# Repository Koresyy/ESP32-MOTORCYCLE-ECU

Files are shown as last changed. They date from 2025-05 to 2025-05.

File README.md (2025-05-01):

# ESP32-MOTORCYCLE-ECU (HARDWARE ONLY)

📌 THIS BOARD IS INTENDED FOR PROTOTYPING PURPOSES ONLY.  
📌 NO SOFTWARE/CODE IS INCLUDED IN THIS REPOSITORY.  
📌 THIS PROJECT FOCUSES EXCLUSIVELY ON THE HARDWARE DESIGN OF A MOTORCYCLE FUEL CONTROL SYSTEM USING ESP32.

## ⚙️ Overview

This project presents a **custom-designed PCB and schematic** for a fuel injection controller using the ESP32 microcontroller. It is suitable for small-displacement motorcycles and is designed with expandability in mind.




### Key Highlights
- Designed to handle RPM, MAP, IAT, TPS sensor inputs
- Injector driver circuit (compatible with Mio J injector)
- Power supply filtering and protection
- UART/I2C communication interface between controllers
- Expansion pins for future modules (e.g., speedometer, data logger)

## 🔒 Disclaimer

🚨 **THIS IS NOT A PRODUCTION-READY ECU.**  
This board is for **educational and prototyping use only**. Use with caution.  
Author is not responsible for any damage caused by misuse or improper wiring.

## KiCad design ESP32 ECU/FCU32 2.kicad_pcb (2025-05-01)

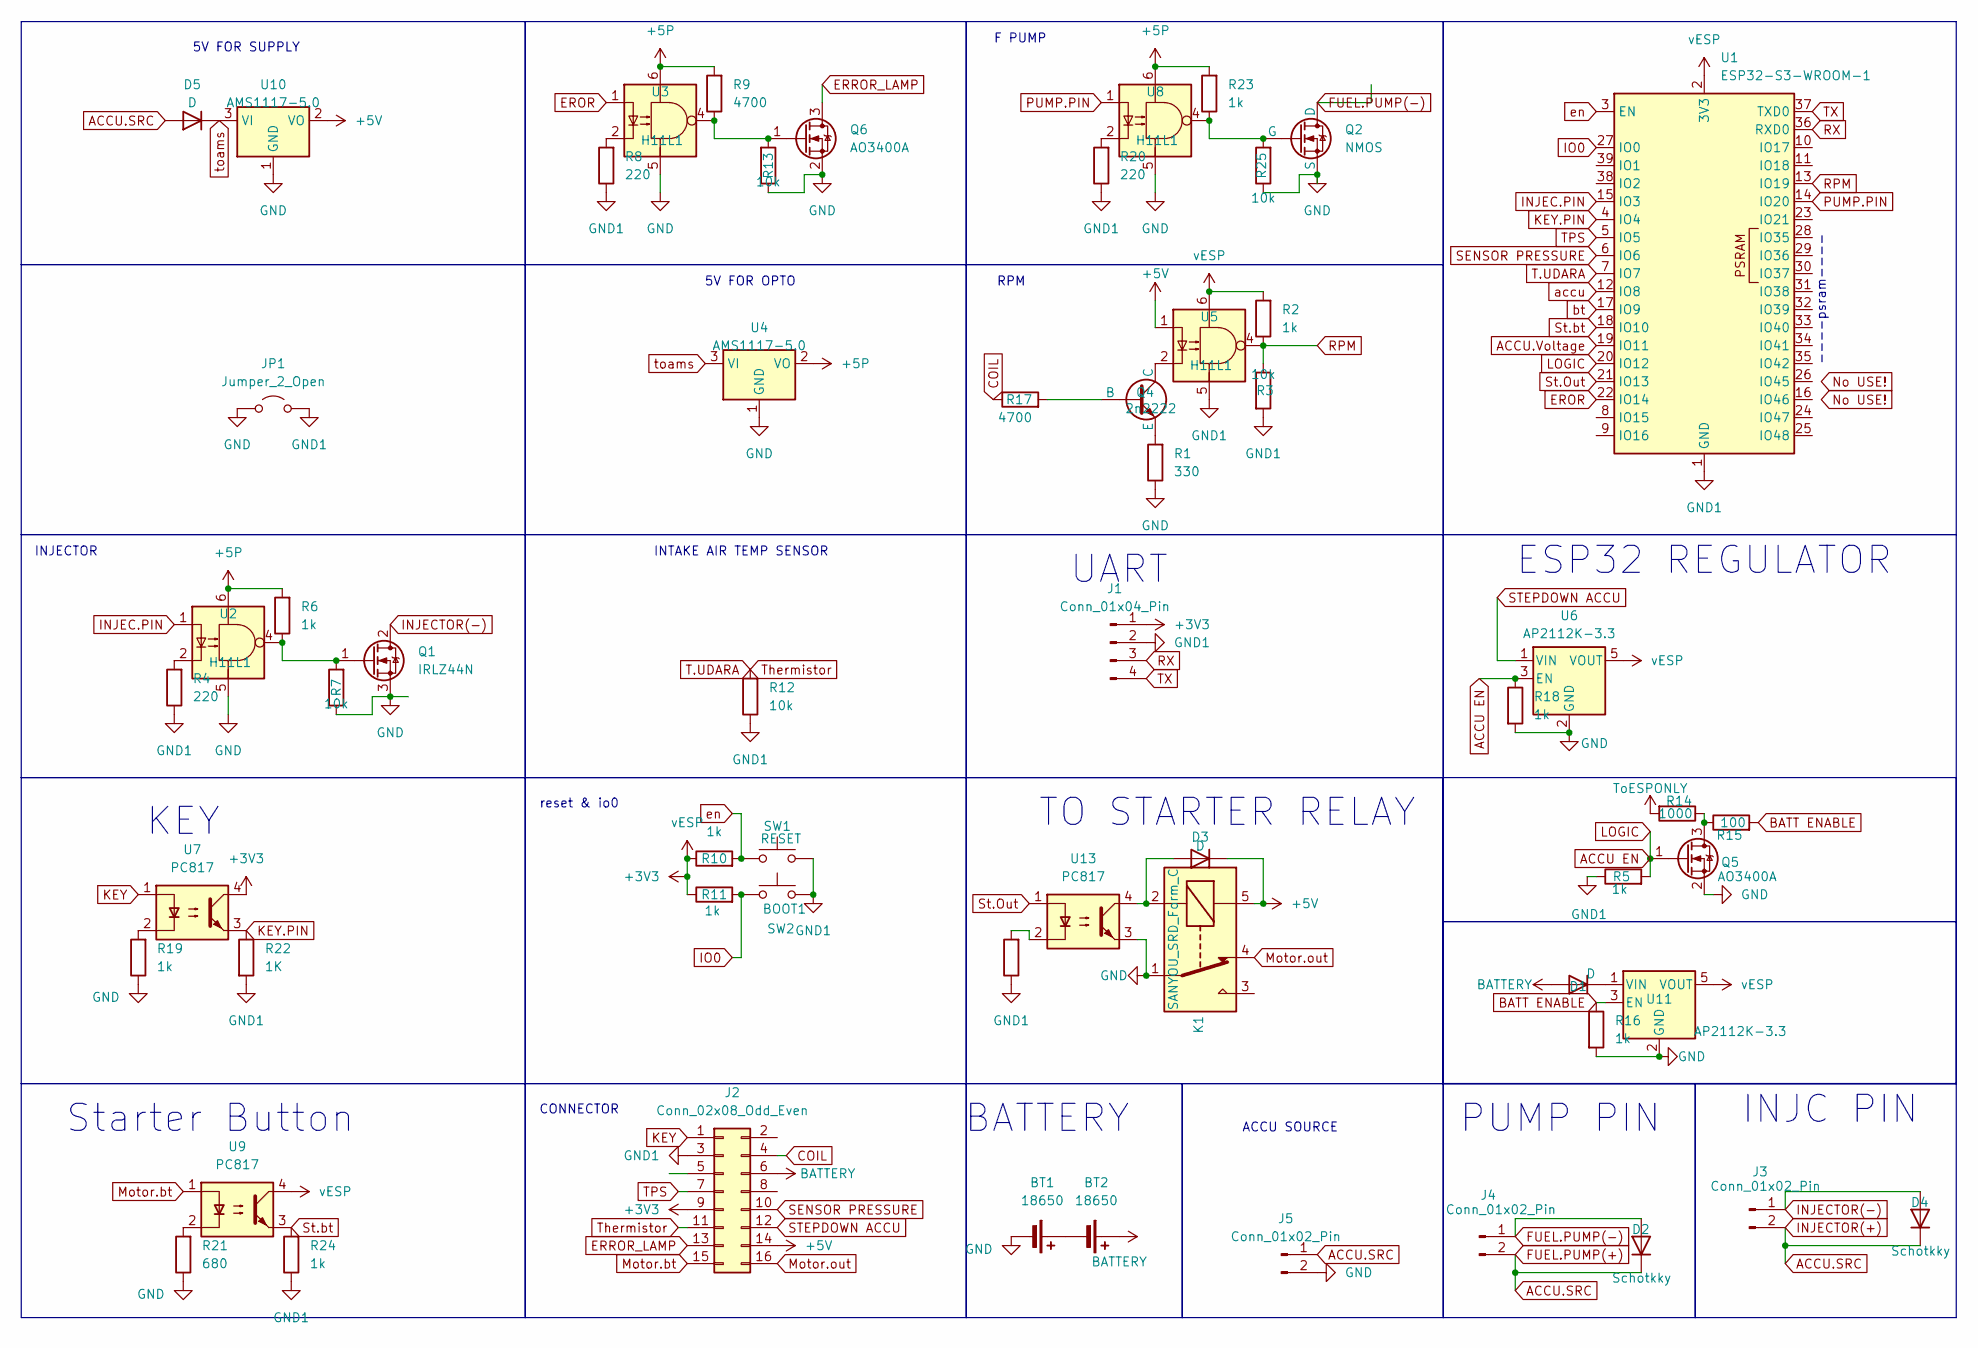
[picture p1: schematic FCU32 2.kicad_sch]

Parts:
BT1, BT2: 18650
D1, D3, D5: D; D_SMA
D2, D4: Schotkky; D_SMA
J1: Conn_01x04_Pin; PinHeader_1x04_P2.54mm_Horizontal
J2: Conn_02x08_Odd_Even; PinHeader_2x08_P2.54mm_Horizontal
J3, J4, J5: Conn_01x02_Pin; AMASS_XT30PW-M_1x02_P2.50mm_Horizontal
JP1: Jumper_2_Open; PinHeader_1x02_P2.54mm_Vertical
K1: SANYOU_SRD_Form_C; Relay_SPDT_SANYOU_SRD_Series_Form_C
Q1: IRLZ44N; TO-220-3_Vertical
Q2: NMOS; TO-252-2
Q4: 2n2222; SOT-23
Q5, Q6: AO3400A; SOT-23
R1: 330; R_1206_3216Metric_Pad1.30x1.75mm_HandSolder
R2, R5, R6, R10, R11, R16, R18, R19, R23, R24: 1k; R_1206_3216Metric_Pad1.30x1.75mm_HandSolder
R3, R7, R12, R13, R25: 10k; R_1206_3216Metric_Pad1.30x1.75mm_HandSolder
R4, R8, R20, R26: 220; R_1206_3216Metric_Pad1.30x1.75mm_HandSolder
R9, R17: 4700; R_1206_3216Metric_Pad1.30x1.75mm_HandSolder
R14: 1000; R_1206_3216Metric_Pad1.30x1.75mm_HandSolder
R15: 100; R_1206_3216Metric_Pad1.30x1.75mm_HandSolder
R21: 680; R_1206_3216Metric_Pad1.30x1.75mm_HandSolder
R22: 1K; R_1206_3216Metric_Pad1.30x1.75mm_HandSolder
SW1: RESET; SW_PUSH_6mm_H4.3mm
SW2: BOOT1; SW_PUSH_6mm_H4.3mm
U1: ESP32-S3-WROOM-1
U2, U3, U5, U8: H11L1; DIP-6_W7.62mm
U4, U10: AMS1117-5.0; SOT-223-3_TabPin2
U6, U11: AP2112K-3.3; SOT-23-5
U7, U9, U13: PC817; DIP-4_W7.62mm

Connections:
+3V3: J1.1, J2.9, R2.2, R10.1, R11.1, U1.2 (3V3), U5.6, U6.5 (VOUT), U7.4, U9.4, U11.5 (VOUT)
+5P: R6.2, R9.2, R23.2, U2.6, U3.6, U4.2 (VO), U8.6
+5V: D3.1 (K), J2.14, K1.5, U5.1, U10.2 (VO)
ACCU EN: Q5.1 (G), R5.2, R18.1, U1.20 (IO12), U6.3 (EN)
ACCU.SRC: D2.1 (K), D4.1 (K), D5.2 (A), J3.2, J4.2, J5.1
ACCU.Voltage: U1.19 (IO11)
BATT ENABLE: R15.2, R16.1, U11.3 (EN)
BATTERY: BT2.1 (+), D1.2 (A), J2.6
COIL: J2.4, R17.1
EROR: U1.22 (IO14), U3.1
ERROR_LAMP: J2.13, Q6.3 (D)
FUEL.PUMP(-): D2.2 (A), J4.1, Q2.1 (D)
GND: BT1.2 (-), J5.2, JP1.1 (A), K1.1, Q1.3 (S), Q2.3 (S), Q5.2 (S), Q6.2 (S), R1.1, R7.1, R13.1, R16.2, R18.2, R19.1, R21.1, R25.1, U2.5, U3.5, U4.1 (GND), U6.2 (GND), U8.5, U10.1 (GND), U11.2 (GND), U13.3
GND1: J1.2, J2.3, JP1.2 (B), R3.2, R4.1, R5.1, R8.1, R12.1, R20.1, R22.2, R24.1, R26.1, SW1.2, SW2.2, U1.1 (GND), U1.40 (GND), U1.41 (GND), U5.5
INJEC.PIN: U1.15 (IO3), U2.1
INJECTOR(-): D4.2 (A), J3.1, Q1.2 (D)
IO0: R11.2, SW2.1, U1.27 (IO0)
KEY: J2.1, U7.1
KEY.PIN: R22.1, U1.4 (IO4), U7.3
Motor.bt: J2.15, U9.1
Motor.out: J2.16, K1.4
unnamed: BT1.1 (+), BT2.2 (-)
unnamed: D1.1 (K), U11.1 (VIN)
unnamed: D3.2 (A), K1.2, U13.4
unnamed: Q1.1 (G), R6.1, R7.2, U2.4
unnamed: Q2.2 (G), R23.1, R25.2, U8.4
unnamed: Q4.2 (B), R17.2
unnamed: Q4.1 (C), U5.2
unnamed: Q4.3 (E), R1.2
unnamed: Q5.3 (D), R14.1, R15.1
unnamed: Q6.1 (G), R9.1, R13.2, U3.4
unnamed: R4.2, U2.2
unnamed: R8.2, U3.2
unnamed: R19.2, U7.2
unnamed: R20.2, U8.2
unnamed: R21.2, U9.2
unnamed: R26.2, U13.2
PUMP.PIN: U1.14 (IO20), U8.1
RPM: R2.1, R3.1, U1.13 (IO19), U5.4
RX: J1.3, U1.36 (RXD0)
SENSOR PRESSURE: J2.10, U1.6 (IO6)
STEPDOWN ACCU: J2.12, U6.1 (VIN)
St.Out: U1.21 (IO13), U13.1
St.bt: R24.2, U1.18 (IO10), U9.3
T.UDARA: J2.11, R12.2, U1.7 (IO7)
TPS: J2.7, U1.5 (IO5)
TX: J1.4, U1.37 (TXD0)
ToESPONLY: R14.2
accu: U1.12 (IO8)
bt: U1.17 (IO9)
en: R10.2, SW1.1, U1.3 (EN)
toams: D5.1 (K), U4.3 (VI), U10.3 (VI)

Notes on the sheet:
ACCU SOURCE
reset & io0
Starter Button
ESP32 REGULATOR
----psram----
UART
TO STARTER RELAY
INJC PIN
5V FOR OPTO
F PUMP
5V FOR SUPPLY
INTAKE AIR TEMP SENSOR
PUMP PIN
CONNECTOR
BATTERY
INJECTOR
KEY
RPM

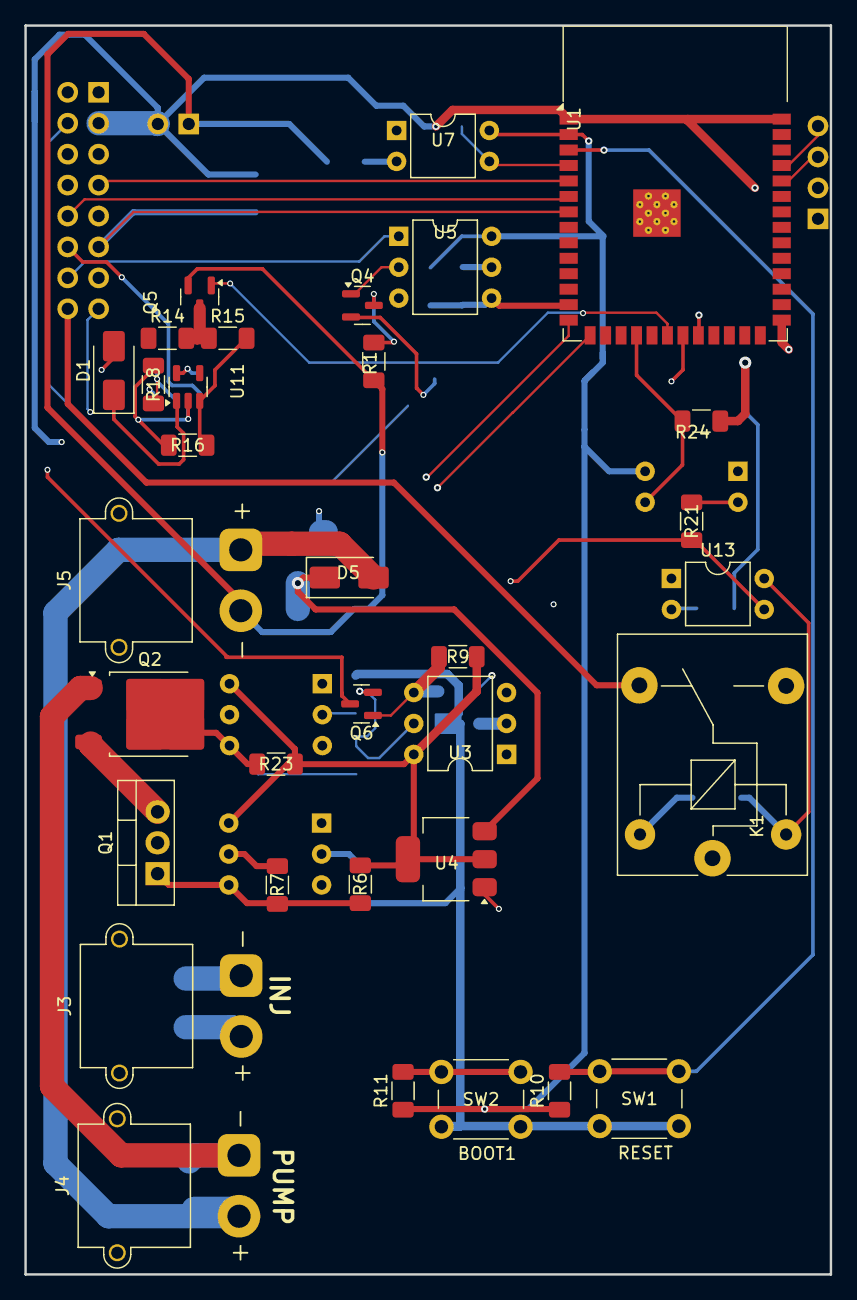
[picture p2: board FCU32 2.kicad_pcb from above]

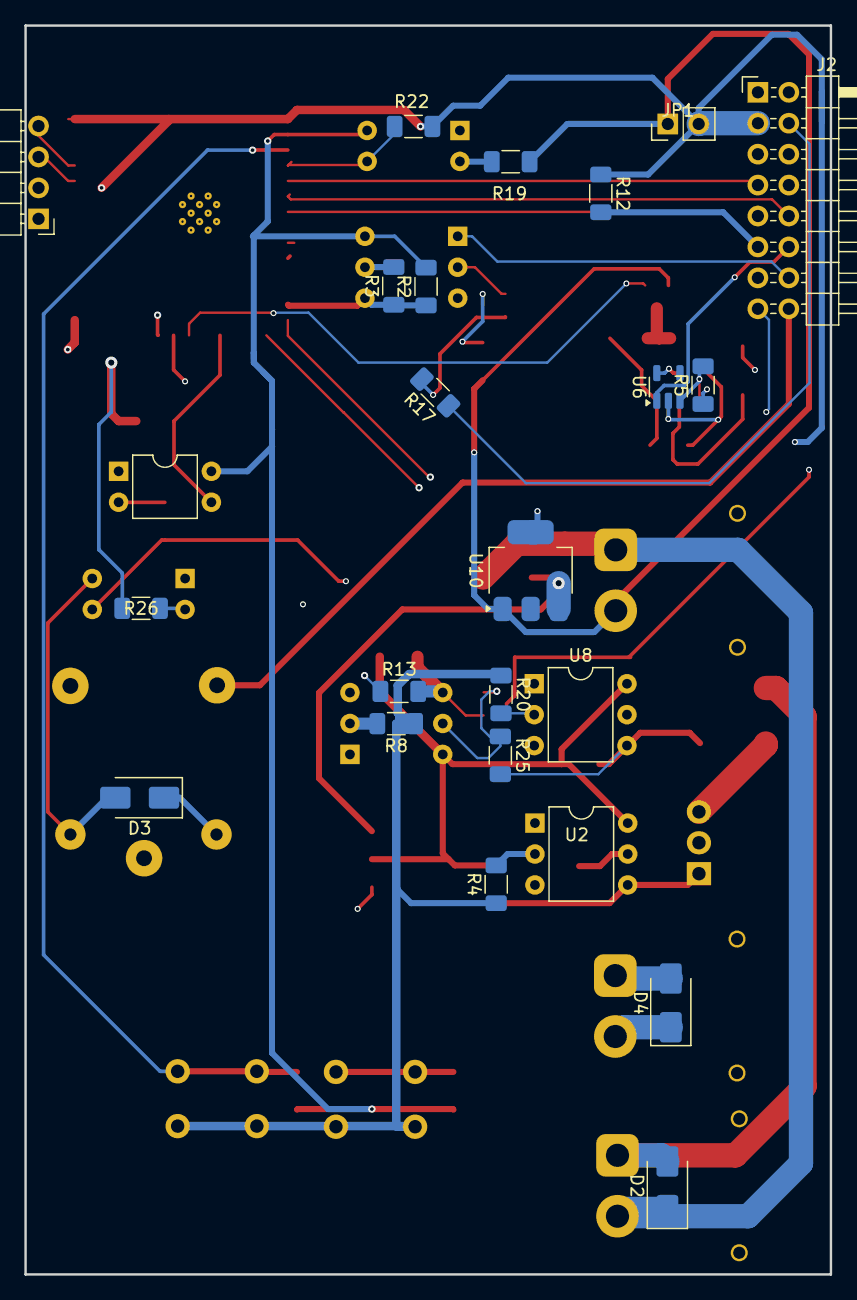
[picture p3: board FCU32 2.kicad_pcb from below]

Board: 4 copper layers, 66.1 x 102.6 mm, 57 parts (24 on the bottom side), 47 nets.
